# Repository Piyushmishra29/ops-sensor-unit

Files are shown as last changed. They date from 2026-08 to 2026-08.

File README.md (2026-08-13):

# OPS Sensor Unit

A rugged, field-style desk monitor for **air quality, temperature and humidity** — ESP32 + 1.3" OLED + MQ-135 + DHT11, in a 3D-printed enclosure designed around the actual parts rather than around a render.

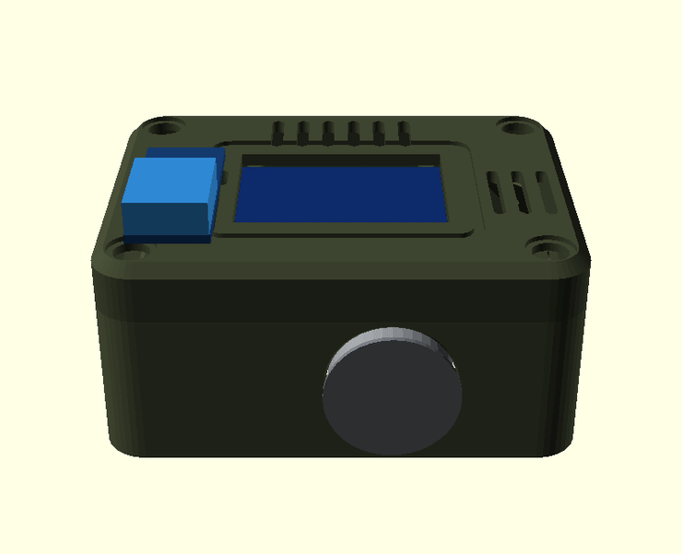
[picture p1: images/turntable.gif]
Assembled unit


**77.8 × 59.3 × 35.7 mm · two printed parts · ~44 g of filament · 1 h 23 m to print**

---

## What it measures — and what it doesn't

Being blunt about this up front, because most projects like this aren't:

| Claim | Reality |
|---|---|
| Temperature, humidity | ✅ DHT11 — ±2 °C, ±5 % RH. Coarse but honest. |
| "Air quality" | ⚠️ MQ-135 senses a **mixture of gases** (CO₂, VOCs, smoke, alcohol, NH₃) as a single resistance change. Useful as a *stale-air / smoke* indicator. |
| **AQI / PM2.5** | ❌ **Not possible with these parts.** An MQ-135 cannot see particulates. Anything labelling its output "AQI" is inventing a number. |

The firmware therefore reports an **AQ index** with a band (GOOD / FAIR / POOR / BAD), never a fake PM2.5 figure. If you want real PM2.5, add a PMS5003 or SDS011 — there is room in the case.

The MQ-135 also needs **24–48 h of burn-in** when new, and a few minutes of heater warm-up on every boot. The firmware shows a warm-up screen and refuses to present a reading as trustworthy before then.

---

## The enclosure

| | |
|---|---|
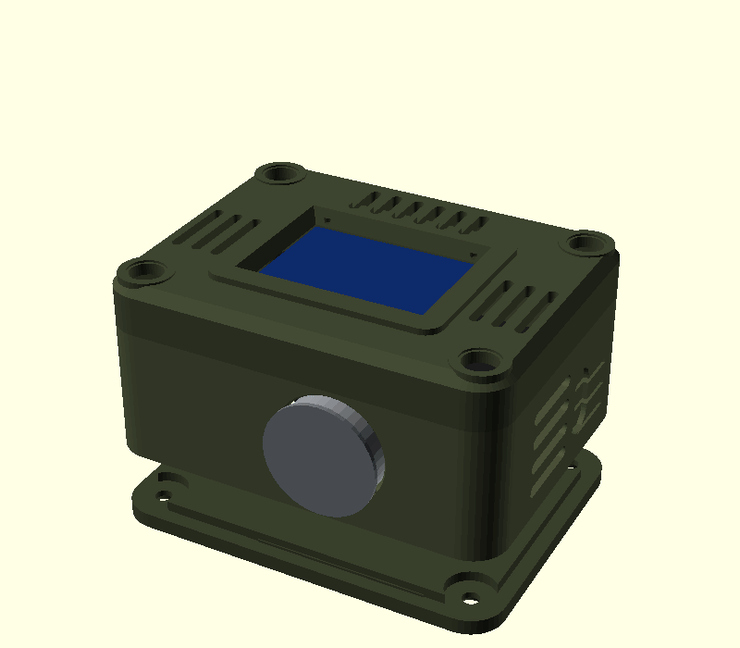
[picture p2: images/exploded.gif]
Exploded
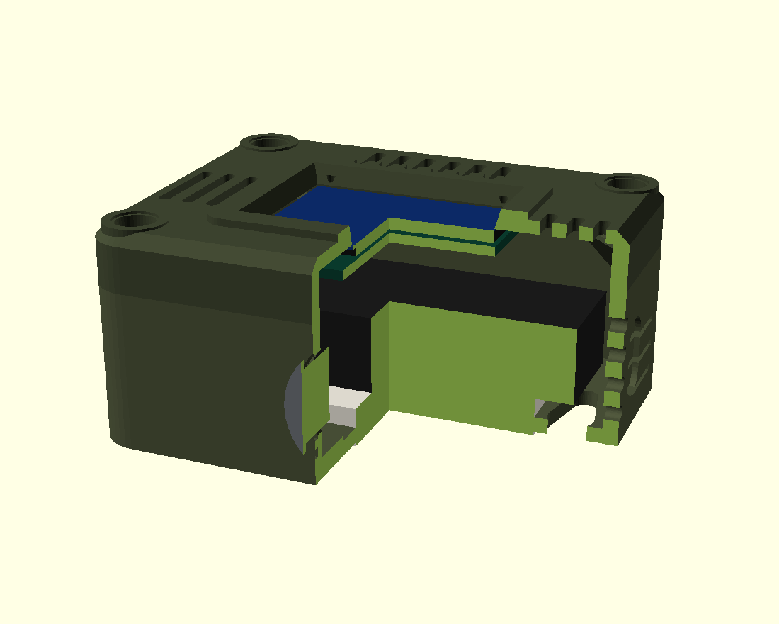
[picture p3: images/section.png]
Section
|  |  |
| Two-part shell: base tub + top cover, four M3 × 5 screws | Sectioned — the electronics are fully enclosed |
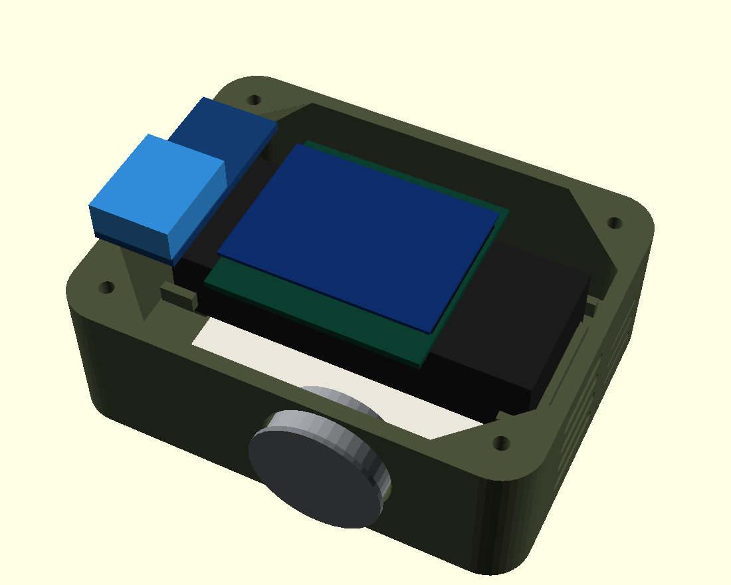
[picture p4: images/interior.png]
Interior
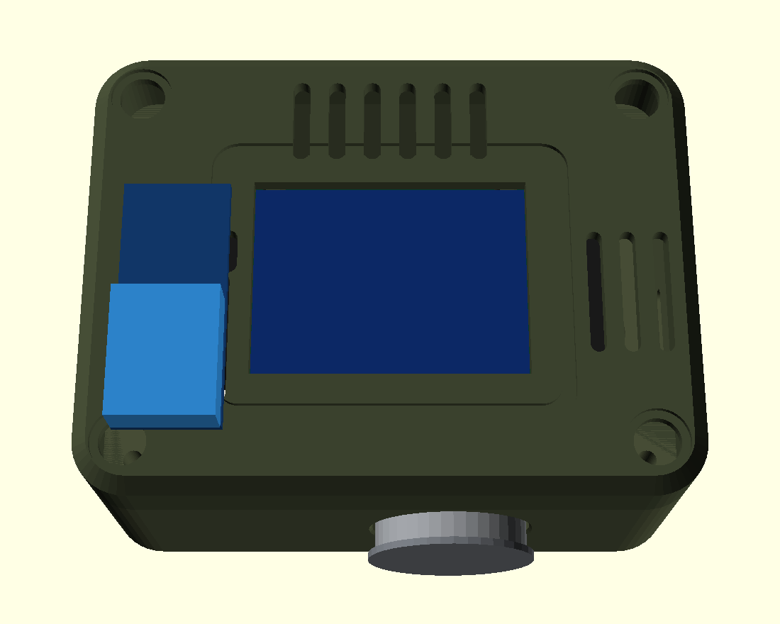
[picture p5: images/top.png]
Top
|  |  |
| Breadboard corner brackets, sensor supports, corner webs | Display window, vent fields, recessed screw pads |

**Design decisions worth knowing:**

- **Corner screw webs, not towers.** Each corner has a triangular gusset welded into the two walls — 13 mm legs tapering to 4 mm over 9 mm of height, a 45° self-supporting underside. 0.36 cm³ each instead of 1.56 cm³ as a column.
- **Sensors on perpendicular walls.** The MQ-135's heater runs hot enough to corrupt a nearby humidity reading, so the DHT11 sits on the left flank, 49 mm away, with its own vent field.
- **Breadboard is captive.** Four L-brackets hug the board's footprint with 0.3 mm clearance, on a raised pad.
- **Nothing needs support.** Both plates print flat as oriented.

### Dimensions

| Feature | Value |
|---|---|
| Outer | 77.8 × 59.3 × 35.7 mm |
| Interior | 72.6 × 54.1 × 28.5 mm |
| Wall / floor | 2.6 mm |
| Parting line | 26.1 mm |
| Display window | 34.8 × 25.8 mm |
| MQ-135 port | Ø20.8 mm, axis at z = 14.5 |
| USB-C | 13 × 7.4 mm racetrack, centre z = 12.3 |
| Fasteners | 4 × M3 × 5, self-tapping into the webs |

---

## Verification

The geometry was audited rather than eyeballed, because an earlier version of this design had seven clearance failures that only showed up under measurement:

- **47 parametric checks** across shell, component fit, display, sensors, ports, fasteners and floor features — all pass.
- **Mesh topology** — every part checked edge-by-edge: zero open, odd-count or non-manifold edges.
- **Cross-section scans** at four heights, hunting for unintended openings. The only enclosed voids are the two wall-mount keyholes.
- **Headless slice** of both plates: exit 0, no supports, 29.2 g / 52 min and 15.2 g / 31 min.

Defects this process caught and fixed: MQ-135 module passing through the floor, its port breaking the parting line, the module colliding with a corner post, the cavity eating the screw posts, blind screw bores creating sealed voids, louvre slots shooting out through the rear corners, USB-C 3 mm below the devkit's connector, keyholes sitting under the breadboard, and 0.77 mm of deck between the display window and a vent field.

---

## Printing

`print/OPS_ENCLOSURE_P2S.3mf` — Bambu Lab P2S, 0.2 mm, PLA, 3 walls, 20 % infill, 3 mm brim.

| Plate | Contents | Weight | Time |
|---|---|---|---|
| 1 | Base tub | 29.2 g | 52 min |
| 2 | Top cover + OLED clamp | 15.2 g | 31 min |

**Print plate 1 first and test-fit your components before committing to plate 2.** The enclosure is dimensioned from datasheet values for the devkit, MQ-135 and DHT11 modules; only the breadboard was measured from a real scan. See *Assumptions* below.

STLs are in `stl/`, and the parametric source is `cad/ops_unit.scad` — every dimension derives from the component constants at the top of that file, so changing a module size re-solves the case.

```bash
openscad -o base.stl  -D mode=1 cad/ops_unit.scad   # base tub
openscad -o cover.stl -D mode=2 cad/ops_unit.scad   # top cover
openscad -o clamp.stl -D mode=4 cad/ops_unit.scad   # OLED clamp
```

Modes: `0` assembly · `1` base · `2` cover · `3` exploded · `4` clamp · `7` section · `8` base with electronics.

### Assumptions to verify against your parts

| Part | Assumed | Check |
|---|---|---|
| ESP32-S3 devkit | 63 × 25.5 × 13 mm, USB-C at 12.3 mm | measure connector height |
| OLED | panel 34.8 × 23.2 (measured), M2 pitch 30.5 × 28.5 (assumed) | measure hole pitch |
| MQ-135 module | PCB 32 × 22, can Ø20 | measure |
| DHT11 module | 23 × 12 mm | measure |
| Mini breadboard | 50.14 × 38.54 × 6.5 | ✅ scanned |

---

## Firmware

`firmware/` — MicroPython, no network, no external libraries. See `firmware/README.md` for wiring and flashing.

The SH1106 driver is carried over from the author's *shopkeeper* project and keeps its comments: the 1.3" panel has 132 columns of RAM behind a 128-pixel display (so everything shifts 2 px without an offset), and the panel must be written before it is switched on or a marginal supply browns it out.

---

## Bill of materials

| Item | Notes |
|---|---|
| ESP32-S3 devkit | any board ≤ 63 mm long |
| 1.3" SH1106 OLED, I2C | **not** the 0.96" SSD1306 |
| MQ-135 module | analog output |
| DHT11 module | 3-pin breakout |
| Mini breadboard, 170 tie points | 50 × 38.5 mm |
| 4 × M3 × 5 screws | self-tapping into plastic |
| Jumper wires, USB-C cable | |

## Licence

MIT. Gridfinity-style: use it, change it, sell prints of it.

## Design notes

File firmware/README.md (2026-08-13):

# OPS Sensor Unit — firmware

MicroPython, offline, no external libraries. Verified running on an
**ESP32-WROOM-32D** with MicroPython v1.28.0.

## Wiring (classic ESP32 — NOT S3 pins)

| ESP32 | Component |
|---|---|
| GPIO21 | OLED SDA |
| GPIO22 | OLED SCL |
| 3V3 | OLED VCC + DHT11 VCC |
| GPIO4 | DHT11 DATA |
| GPIO34 | MQ-135 AOUT **via divider** |
| 5V / VIN | MQ-135 VCC (heater needs 5 V) |
| GPIO25 | optional button to GND |
| GND | OLED, DHT11, MQ-135, divider bottom |

**The divider is mandatory.** AOUT swings to 5 V; an ESP32 ADC pin is 3.3 V max.

```
MQ-135 AOUT ──[10k]──┬──► GPIO34
                     │
                  [15k]
                     │
                    GND
```

Pin rules on this chip: **GPIO6–11 are the SPI flash — never use them.**
GPIO0/2/12/15 are strapping pins. GPIO34–39 are input-only (fine for the
MQ-135, useless for the DHT11). The MQ-135 must sit on **ADC1** (GPIO32–39):
ADC2 stops working the moment anyone enables WiFi.

## Flashing

```bash
pip install esptool mpremote
esptool --port /dev/ttyUSB0 erase_flash
esptool --port /dev/ttyUSB0 --baud 460800 write_flash -z 0x1000 ESP32_GENERIC-*.bin
for f in sh1106.py config.py mq135.py aq.py display.py main.py boot.py; do
  mpremote connect /dev/ttyUSB0 cp $f :
done
mpremote connect /dev/ttyUSB0 run main.py     # or just reset — boot.py→main.py
```

## First run

1. **Warm-up** — 3 minutes on every boot. The display shows a countdown; no
   gas number is presented before it finishes, because a cold element reads
   high and falling.
2. **Burn-in** — a new MQ-135 wants 24–48 h powered before its baseline stops
   wandering. It responds to gas long before that; the absolute numbers just
   keep moving.
3. **Calibrate** — hold the button at boot for 3 s, **outdoors or at an open
   window**. This measures R0 against outdoor background CO₂ (421 ppm).
   Calibrating in a closed room bakes that room in and the unit reads it as
   perfect forever. Note a HEPA purifier's output is *not* a substitute: it
   removes particles and VOCs, not CO₂.

## What it measures

Temperature and humidity honestly (±2 °C, ±5 % RH). For air it reports an
**AQ index 0–100 with a band** (GOOD/FAIR/POOR/BAD) derived from Rs relative
to calibration-day Rs — a relative, single-sensor indicator of reducing gases
(CO₂, VOCs, smoke, alcohol, ammonia).

**It is not an AQI and cannot be.** An MQ-135 cannot see particulates. See the
comment block at the top of `aq.py`. Add a PMS5003/SDS011 for real PM2.5.

## Files

| File | Role |
|---|---|
| `config.py` | every pin, constant and threshold, with the reasoning |
| `sh1106.py` | 1.3" OLED driver (from the author's *shopkeeper* project) |
| `mq135.py` | ADC → Rs → Rs/R0 → ppm, calibration, T/RH correction, warm-up gate |
| `aq.py` | Rs → index and band, in log space |
| `display.py` | screens: main, detail, warm-up, calibration |
| `main.py` | init, sensor intervals, history, screen cycling, fault tolerance |

## Measured on hardware

| | |
|---|---|
| OLED | 0x3C on SDA 21 / SCL 22 |
| DHT11 | 27 °C, 62 % RH |
| MQ-135 | 1.54 V idle → Rs ≈ 13 kΩ |
| Filtered air vs room air | Rs **+11.7 %** in filtered air — correct polarity |

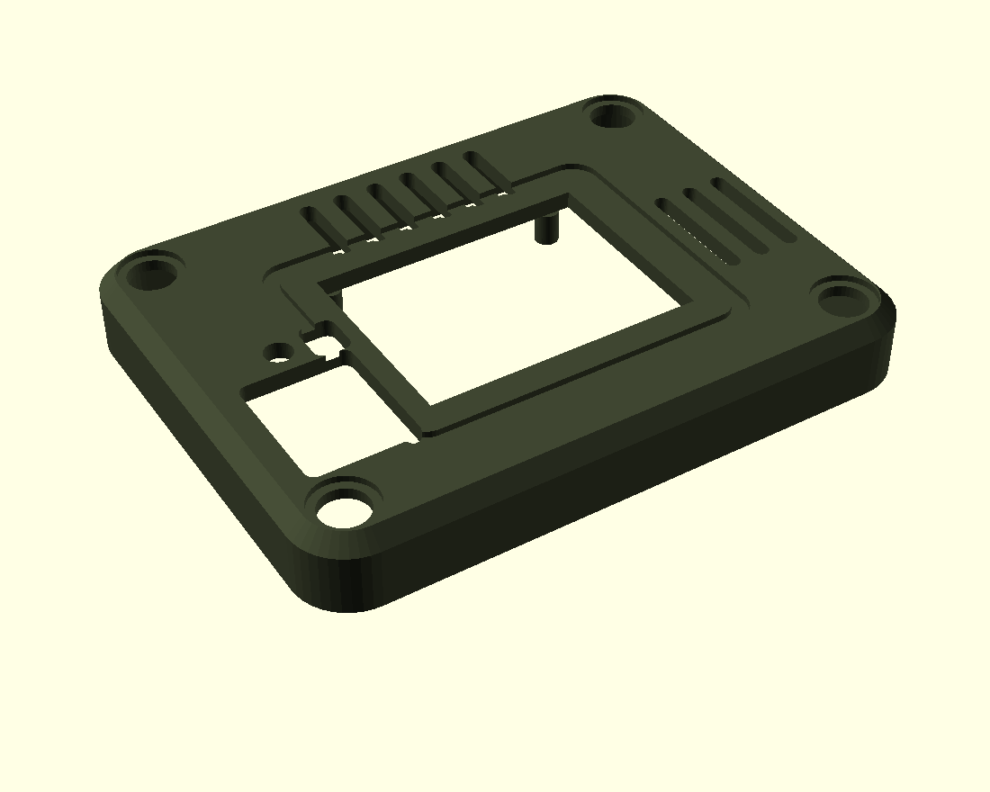
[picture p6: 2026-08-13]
images/cover.png

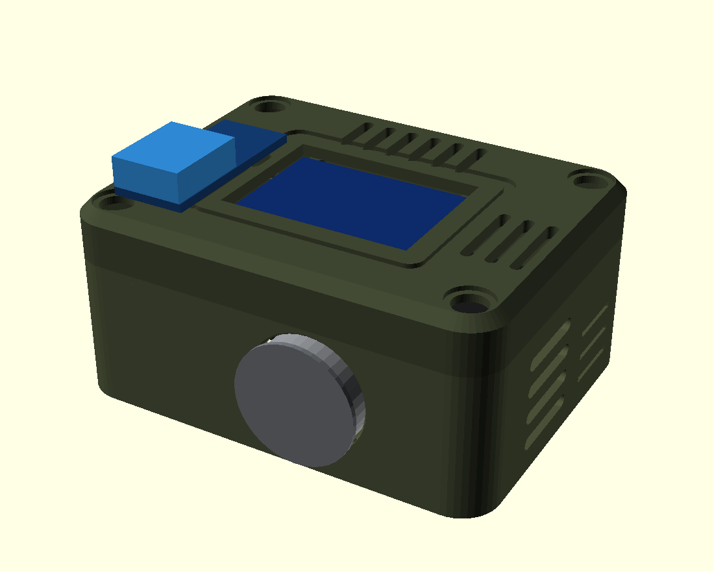
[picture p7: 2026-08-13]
images/hero.png

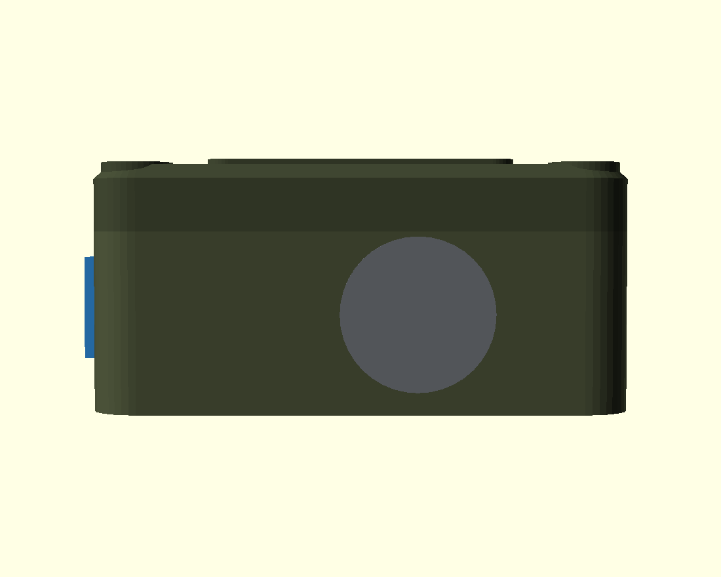
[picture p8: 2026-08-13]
images/front.png

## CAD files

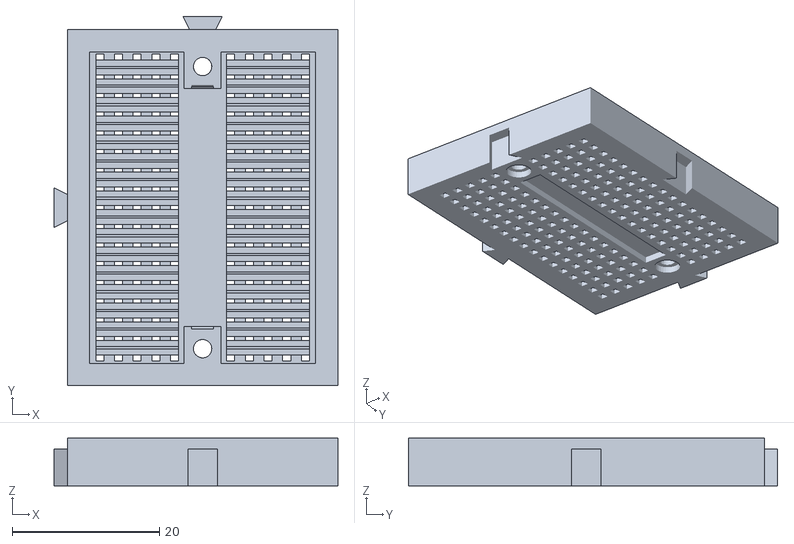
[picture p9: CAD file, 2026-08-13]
cad/breadboard_reference.stl
38.5 x 50.1 x 6.50

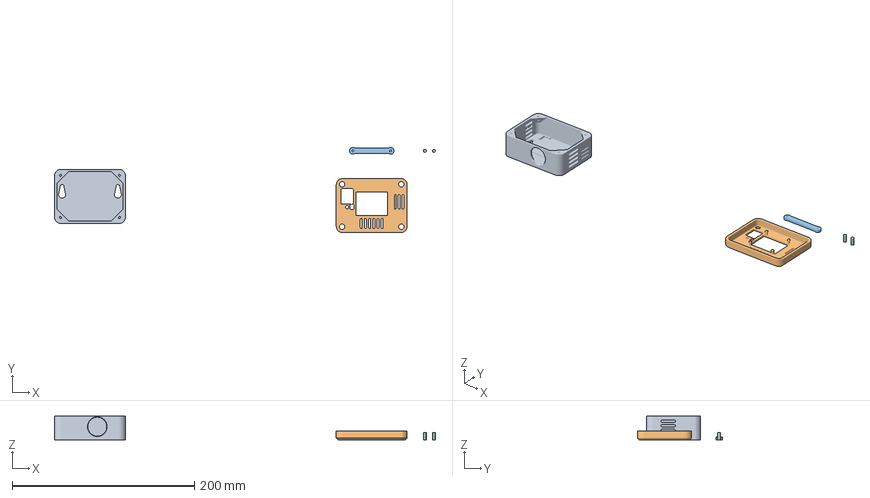
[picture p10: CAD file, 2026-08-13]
print/OPS_ENCLOSURE_P2S.3mf
417.6 x 93.4 x 26.1 mm
Base tub
Top cover
OLED clamp
DHT towers

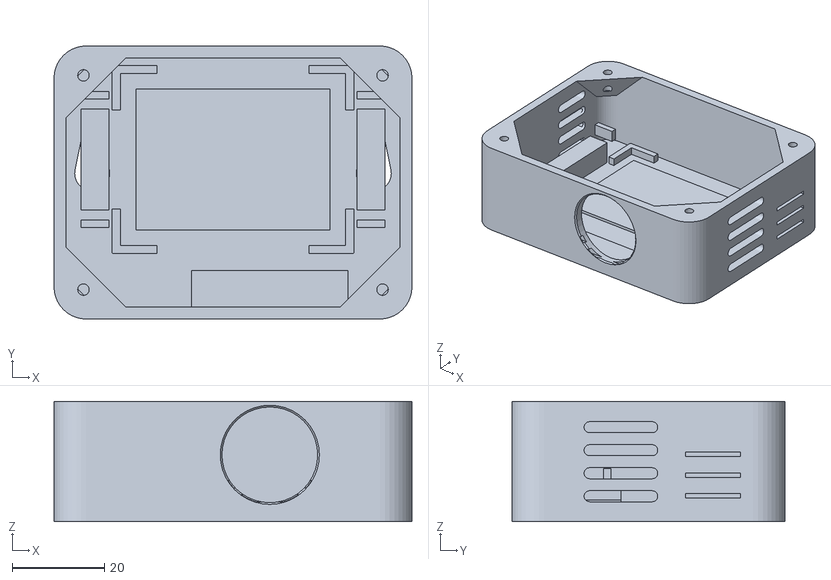
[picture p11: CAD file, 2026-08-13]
stl/ops_base.stl
77.8 x 59.3 x 26.1

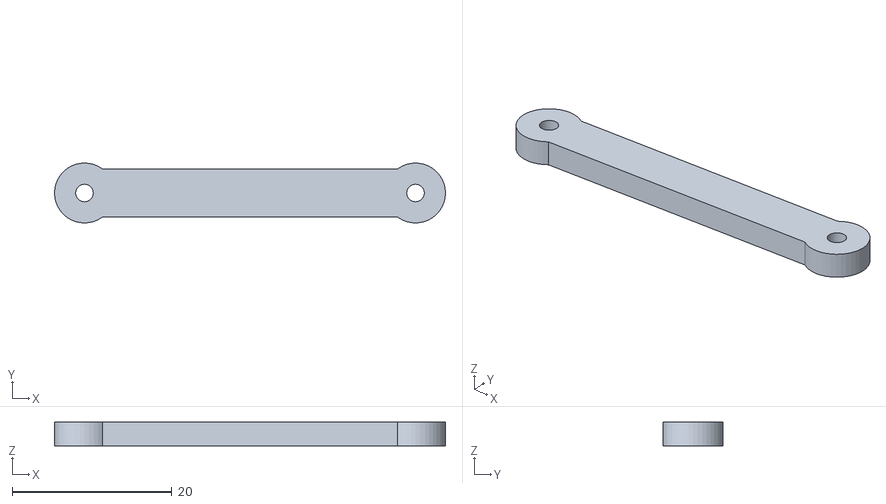
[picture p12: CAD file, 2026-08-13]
stl/ops_clamp.stl
48.9 x 7.50 x 3.00

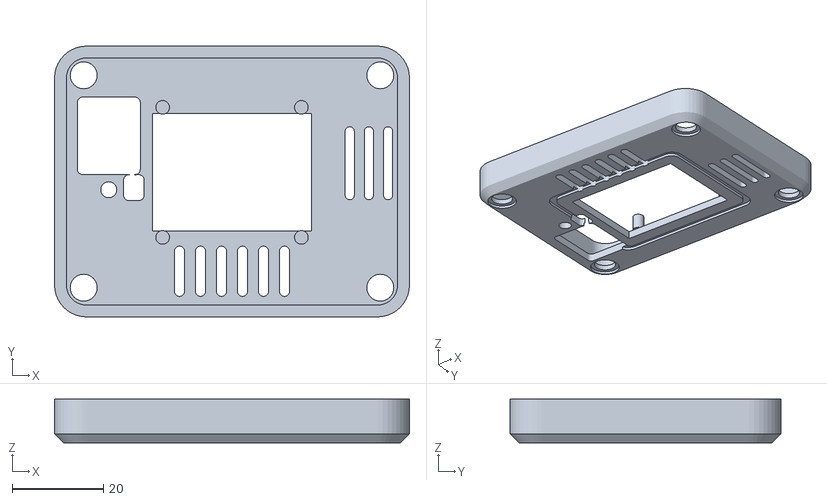
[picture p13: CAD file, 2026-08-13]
stl/ops_cover.stl
77.8 x 59.3 x 9.60

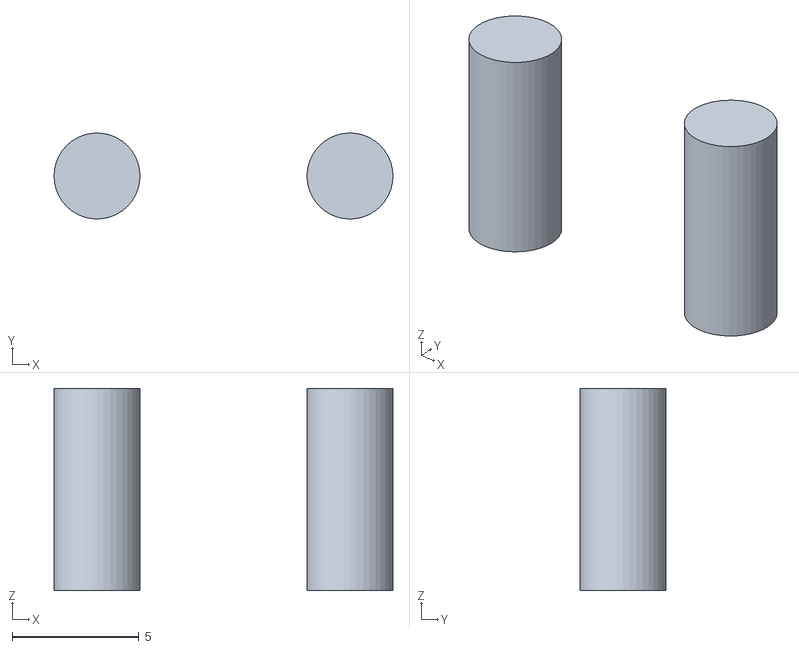
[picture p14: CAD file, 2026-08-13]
stl/ops_spacers.stl
13.4 x 3.40 x 8.00

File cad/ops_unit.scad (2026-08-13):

// ===========================================================================
// OPS SENSOR UNIT — ESP32 environmental monitor
// mode: 0 assembly | 1 base only | 2 cover only | 3 exploded
// ===========================================================================
mode = 0;
EXPLODE = 34;   // exploded-view gap, animatable
$fn = 40;

// ---- real component data --------------------------------------------------
BB      = [50.14, 38.54, 6.50];   // mini breadboard (bread.stl, measured)
ESP     = [63.0, 25.5, 13.0];     // ESP32-S3 DevKitC seated on the breadboard
// 1.3" SH1106 module. These are the MANUFACTURER'S DRAWING figures carried
// over from the author's shopkeeper project, where two caliper readings were
// proved wrong on the bench: the holes are 3.00 (M3) and the 4.0-4.5 reading
// was the copper annulus around them, and the board is 35.40 wide not 35.0.
OLED_PCB   = [35.40, 33.50, 1.20];
OLED_PANEL = [34.50, 23.00];      // glass, standing 1.4-1.5 proud of the PCB
OLED_GLASS = [34.8, 25.8];        // the cutout: clears the glass on both axes
OLED_HOLES = [30.40, 28.50];      // 2.50 inset all round: 35.40-5.00, 33.50-5.00
OLED_HOLE_D = 3.30;               // M3 clearance. NOT M2 - this cost a print once
// The display screws to four printed pillars hanging from the inside of the
// deck, rather than resting on a ledge. Printed deck-down the pillars point
// UP, so they cost nothing and need no support.
// The pillars are PEGS that enter the module's own 3.00 holes, not bosses
// sitting beside them: 2.90 across, which is a press fit in a printed 3.00
// hole and still assembles by hand. They locate the board in both axes and
// stop it rotating; the clamp holds it against them.
OLED_PIL_D  = 3.00;               // pushed to 3.00 - the module's hole size
OLED_PIL_H  = 4.2;                // through the 1.20 board, standing proud
// The active area is 29.42 x 14.70 and is NOT centred: it sits 2.05mm toward
// the header edge, because the driver IC and FPC bond eat the bottom 6.20mm of
// the glass. The cutout is 25.8 tall against a 14.70 active area, so the offset
// is absorbed - but a tight symmetric window would clip the status line.
MQ_CAN_D   = 20.0;                // MQ-135 steel can (protrudes, "half exposed")
MQ_PCB     = [32.0, 22.0, 2.0];
DHT_BODY   = [15.5, 12.0, 5.5];   // DHT11 blue body (protrudes)
DHT_PCB    = [23.0, 12.0, 2.0];

// ---- shell -----------------------------------------------------------------
WALL   = 2.6;
GAP    = 0.8;                     // wiring slack around the breadboard
FLOOR  = 2.6;
CORNER = 7.0;                     // corner radius, drives the rugged look
BOSS_IN = 1.8;                    // boss inset: keeps the screw well out of the cavity
BOSS_R = 4.6;                     // corner boss: sized for M3, not oversized
PLATE_T = 3.0;                    // bottom cover thickness
PLATE_CLR = 0.25;                 // slip fit of the plate into the body

// interior sized from the stack, not guessed
// ---- solved from the tolerance audit, not guessed ------------------------
IN  = [max(BB[0], ESP[0]) + 2*GAP + 8,      // 72.6  devkit + 4.8/side
       BB[1] + 2*GAP + 14,                  // 54.1  incl. 12.8mm front sensor bay
       BB[2] + ESP[2] + 9];                 // 28.5  display clears the devkit by 6.6
OUT = [IN[0] + 2*WALL, IN[1] + 2*WALL, IN[2] + FLOOR + WALL + 2];
SENS_AX = FLOOR + 11.9;                     // 14.5 sensor axis: port clears floor by 1.5
SPLIT   = SENS_AX + 11.6;                   // 26.1 MQ port sits wholly inside the base wall
BB_Y    = 5.0;                              // breadboard centre, 2.8mm rear gap

echo(str("OLED underside ", OUT[2]-WALL-4.4, "  vs devkit top ", FLOOR+BB[2]+ESP[2], " mm"));
echo(str("OUTER  ", OUT[0], " x ", OUT[1], " x ", OUT[2], " mm"));

// rounded slab: hull of 4 vertical cylinders
module rslab(sz, r, ch=0){
  hull() for(sx=[-1,1], sy=[-1,1])
    translate([sx*(sz[0]/2-r), sy*(sz[1]/2-r), 0])
      cylinder(h=sz[2], r=r);
}
// same but with a chamfered top edge (tapers in by `ch`)
module rslab_ch(sz, r, ch=1.6){
  hull(){
    rslab([sz[0], sz[1], sz[2]-ch], r);
    translate([0,0,sz[2]-ch]) rslab([sz[0]-2*ch, sz[1]-2*ch, ch], max(r-ch,0.6));
  }
}
// Screw corners are triangular webs spanning the two walls, not towers off the
// floor. Top face is full size, underside tapers 45 deg so it self-supports.
WEB_L = 13.0;    // leg length at the top
WEB_H = 9.0;     // height of the web (bottom legs = WEB_L - WEB_H -> 45 deg)
module corner_web(sx, sy, top){
  cx = sx*(OUT[0]/2-WALL); cy = sy*(OUT[1]/2-WALL);
  translate([cx, cy, top-WEB_H])
    hull(){
      translate([0,0,WEB_H-0.01])
        linear_extrude(0.01) polygon([[0,0], [-sx*WEB_L,0], [0,-sy*WEB_L]]);
      linear_extrude(0.01)
        polygon([[0,0], [-sx*(WEB_L-WEB_H),0], [0,-sy*(WEB_L-WEB_H)]]);
    }
}
module corner_bosses(h, r=BOSS_R, inset=BOSS_IN){
  for(sx=[-1,1], sy=[-1,1]) corner_web(sx, sy, h);
}
// M3 x 5 screws: only 2.0mm of cover under the head, so 3.0mm bites the post
module corner_screws(z0, deep=true){
  for(sx=[-1,1], sy=[-1,1])
    translate([sx*(OUT[0]/2-BOSS_R-BOSS_IN), sy*(OUT[1]/2-BOSS_R-BOSS_IN), 0]){
      translate([0,0,z0]) cylinder(h=40, d=3.2);                        // M3 shank, close clearance
      if(deep){
        translate([0,0,OUT[2]-7.6]) cylinder(h=9, d=5.9);               // head well: M3 cap is 5.5, pan 5.6
        translate([0,0,OUT[2]-8.5]) cylinder(h=1.0, d1=3.2, d2=5.9);
      }
    }
}
// Corner pads, cut INTO the deck rather than standing proud of it. Raised pads
// would be the only thing touching the plate when the cover prints face-down,
// which is the orientation that needs no support.
module corner_pads(){ }
module corner_pad_cuts(){
  for(sx=[-1,1], sy=[-1,1])
    translate([sx*(OUT[0]/2-BOSS_R-BOSS_IN), sy*(OUT[1]/2-BOSS_R-BOSS_IN), OUT[2]-0.8])
      difference(){ cylinder(h=2, r=BOSS_R-0.6); translate([0,0,-0.1]) cylinder(h=3, r=BOSS_R-2.1); }
}
// slots in a side wall: stacked in Z, running along Y, cutting through X
module louvres(n=5, len=17, w=2.2, pitch=4.4){
  for(i=[0:n-1]) translate([0, 0, (i-(n-1)/2)*pitch])
    hull() for(sy=[-1,1]) translate([0, sy*(len/2-w/2), 0])
      rotate([0,90,0]) cylinder(h=30, d=w, center=true);
}
// slots in the top skin: spaced in X, running along Y, cutting through Z
module top_slots(n=4, len=16, w=2.2, pitch=4.6){
  for(i=[0:n-1]) translate([(i-(n-1)/2)*pitch, 0, 0])
    hull() for(sy=[-1,1]) translate([0, sy*(len/2-w/2), 0]) cylinder(h=20, d=w, center=true);
}
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

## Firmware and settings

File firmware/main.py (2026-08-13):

"""
OPS Sensor Unit — main loop.

Shape of the thing:

    boot   -> bring up display, gas sensor, DHT11. None of them is allowed to
              be fatal: a unit with a dead screen must still sample, and a unit
              with a dead sensor must still say so on the screen.
    loop   -> poll each sensor on its own interval (the DHT11 cannot be rushed),
              fold the readings into one state dict, hand that to display.py.
    faults -> counted, not raised. A jumper that falls out mid-shift should
              degrade the display, not stop the device.

Timing is interval-based rather than sleep-based so that a slow DHT11 read
(they block for ~25 ms and sometimes much longer) does not drag the display
refresh with it.
"""
import gc
import sys
import time

from machine import Pin

import config
import aq
import display as ui
import mq135
import sh1106


# ── hardware, each optional ────────────────────────────────────────────────
def _init_display():
    try:
        d = sh1106.attach()
        if d:
            d.contrast(config.OLED_CONTRAST)
            d.fill(0)
            d.text("OPS SENSOR", 24, 20)
            d.text(config.FW, 48, 34)
            d.show()
        return d
    except Exception as e:
        print("display init failed:", e)
        return None


def _init_dht():
    """DHT11 on a bidirectional pin. Import guarded because a board without the
    dht module should still run the gas sensor."""
    try:
        import dht
        return dht.DHT11(Pin(config.DHT_PIN))
    except Exception as e:
        print("dht init failed:", e)
        return None


def _init_button():
    if config.BUTTON_PIN is None:
        return None
    try:
        return Pin(config.BUTTON_PIN, Pin.IN, Pin.PULL_UP)
    except Exception as e:
        print("button init failed:", e)
        return None


def _pressed(btn):
    if btn is None:
        return False
    v = btn.value()
    return (v == 0) if config.BUTTON_ACTIVE_LOW else (v == 1)


# ── calibration entry point ────────────────────────────────────────────────
def _maybe_calibrate(mq, d, btn):
    """Hold the button at boot to re-measure R0 in clean air.

    Deliberately gated behind a hold rather than a tap: calibrating in the
    wrong air bakes a bad baseline into every later reading, and it is the one
    action here that is hard to undo without a serial console.
    """
    if not _pressed(btn):
        return
    t0 = time.ticks_ms()
    while _pressed(btn):
        held = time.ticks_diff(time.ticks_ms(), t0) // 1000
        if d:
            d.fill(0)
            d.text("HOLD TO CAL", 20, 18)
            d.big(str(max(0, config.BUTTON_CAL_HOLD_S - held)), 56, 32, 2)
            d.show()
        if held >= config.BUTTON_CAL_HOLD_S:
            break
        time.sleep_ms(100)
    else:
        return                                  # released early: do nothing

    def progress(i, n, good):
        if d:
            ui.screen_cal(d, None, max(0, n - i), "%d ok" % good)
            d.show()

    try:
        r0, note = mq.calibrate(progress=progress)
        print("calibrated R0=%s (%s)" % (r0, note))
        if d:
            d.fill(0)
            d.text("CALIBRATED", 24, 20)
            d.text("R0 %d" % (r0 or 0), 32, 34)
            d.show()
            time.sleep(2)
    except Exception as e:
        print("calibration failed:", e)
        if d:
            d.fill(0); d.text("CAL FAILED", 24, 24); d.text(str(e)[:16], 0, 40)
            d.show(); time.sleep(3)


# ── main ───────────────────────────────────────────────────────────────────
def main():
    print("OPS Sensor Unit %s  fw %s" % (config.UNIT, config.FW))
    for note in config._self_check():
        print("config:", note)

    d = _init_display()
    mq = mq135.MQ135()
    dht_dev = _init_dht()
    btn = _init_button()
    _maybe_calibrate(mq, d, btn)

    wdt = None
    if config.WDT_ENABLE:
        try:
            from machine import WDT
            wdt = WDT(timeout=config.WDT_TIMEOUT_MS)
        except Exception as e:
            print("wdt unavailable:", e)

    temp = hum = None
    hist = []
    reading = mq.read()
    state = {"aq": aq.summary(reading), "raw": reading, "temp": None,
             "hum": None, "hist": hist, "screen": 0, "uptime_ms": 0}

    t_boot = time.ticks_ms()
    nxt_dht = nxt_mq = nxt_ui = nxt_hist = time.ticks_ms()
    nxt_rot = time.ticks_add(time.ticks_ms(), config.SCREEN_DWELL_S * 1000)
    fail_dht = fail_mq = fail_ui = 0
    btn_was = False

    while True:
        now = time.ticks_ms()

        # ── button: cycle screens, and pause auto-rotation while in use ────
        p = _pressed(btn)
        if p and not btn_was:
            state["screen"] = (state.get("screen", 0) + 1) % len(ui.SCREENS)
            nxt_rot = time.ticks_add(now, config.SCREEN_HOLD_S * 1000)
            nxt_ui = now                        # redraw immediately, feels crisp
        btn_was = p

        if time.ticks_diff(now, nxt_rot) >= 0:
            state["screen"] = (state.get("screen", 0) + 1) % len(ui.SCREENS)
            nxt_rot = time.ticks_add(now, config.SCREEN_DWELL_S * 1000)

        # ── DHT11: slow, fragile, and never allowed to stop the loop ───────
        if time.ticks_diff(now, nxt_dht) >= 0:
            nxt_dht = time.ticks_add(now, config.DHT_INTERVAL_MS)
            if dht_dev:
                try:
                    dht_dev.measure()
                    temp = dht_dev.temperature()
                    hum = dht_dev.humidity()
                    fail_dht = 0
                except Exception:
                    fail_dht += 1
                    if fail_dht >= config.FAIL_LIMIT_SENSOR:
                        temp = hum = None       # stop showing a stale number
            state["temp"], state["hum"] = temp, hum

        # ── MQ-135 ─────────────────────────────────────────────────────────
        if time.ticks_diff(now, nxt_mq) >= 0:
            nxt_mq = time.ticks_add(now, config.MQ_INTERVAL_MS)
            try:
                reading = mq.read(temp, hum)
                state["raw"] = reading
                state["aq"] = aq.summary(reading)
                fail_mq = 0
            except Exception as e:
                fail_mq += 1
                if fail_mq >= config.FAIL_LIMIT_SENSOR:
                    print("mq135 failing:", e)

        # ── history for the sparkline ──────────────────────────────────────
        if time.ticks_diff(now, nxt_hist) >= 0:
            nxt_hist = time.ticks_add(now, config.HISTORY_INTERVAL_S * 1000)
            hist.append(state["aq"].get("index"))
            while len(hist) > config.HISTORY_LEN:
                hist.pop(0)

        # ── draw ───────────────────────────────────────────────────────────
        if d and time.ticks_diff(now, nxt_ui) >= 0:
            nxt_ui = time.ticks_add(now, config.DISPLAY_INTERVAL_MS)
            state["uptime_ms"] = time.ticks_diff(now, t_boot)
            try:
                ui.render(d, state)
                d.show()
                fail_ui = 0
            except Exception as e:
                fail_ui += 1
                if fail_ui >= config.FAIL_LIMIT_DISPLAY:
                    print("display lost:", e)
                    d = None                    # keep sampling without it

        if wdt:
            wdt.feed()
        gc.collect()
        time.sleep_ms(config.LOOP_TICK_MS)


if __name__ == "__main__":
    try:
        main()
    except KeyboardInterrupt:
        print("stopped")
    except Exception:
        # Print the traceback and stop rather than reboot-looping: a unit that
        # reboots every 3 s is much harder to diagnose over a serial console
        # than one sitting at a prompt with the reason on screen.
        sys.print_exception(sys.exc_info()[1]) if hasattr(sys, "exc_info") else None
        raise

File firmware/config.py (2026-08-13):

"""
OPS sensor unit — configuration.

EVERYTHING a given build needs to differ on lives here: pins, the divider
resistors, the gas curve constants, every interval and every threshold. No
other file in this firmware contains a bare number that a person would want to
change. If you find yourself editing mq135.py or display.py to tune something,
that is a bug in this file.

    ┌──────────────────────────────────────────────────────────────────────┐
    │ THE PIN NUMBERS BELOW ARE A CHOICE, NOT A DISCOVERY.                  │
    │ They are sane ESP32-S3 defaults picked to avoid the strapping pins,   │
    │ the USB pins and the SPI-flash pins - but the firmware cannot see     │
    │ your breadboard. Make these match your wiring, or make your wiring    │
    │ match these. Nothing here is auto-detected except the OLED's I2C      │
    │ address.                                                             │
    └──────────────────────────────────────────────────────────────────────┘

Calibration (R0) is NOT in this file. It is measured per unit, per sensor, in
clean air, and persisted to /data/cal.json - because R0 is a property of the
individual bead you soldered, not of the design. See mq135.calibrate().

MicroPython note: this module is imported very early, so it must not touch
`machine` or any hardware. It is arithmetic and constants only.
"""
import math


# ── identity ───────────────────────────────────────────────────────────────
UNIT = "OPS-0001"
FW = "1.0.0"

DATA_DIR = "/data"


# ══ PINS ═══════════════════════════════════════════════════════════════════
# BOARD: ESP32-WROOM-32D  (classic Xtensa dual-core ESP32, NOT an S3).
# The two parts have completely different pinouts, so these numbers are not
# interchangeable with S3 examples found online.
#
# Pins deliberately avoided on this part, and why:
#   GPIO6..GPIO11    SPI flash. Connecting ANYTHING here stops the board
#                    booting. This is the one mistake that looks like a dead
#                    board rather than a wiring error.
#   GPIO0, 2, 12, 15 strapping pins, sampled at reset. Held wrong, the board
#                    either drops into the bootloader or refuses to start.
#                    GPIO12 in particular sets flash voltage - pulling it high
#                    at boot can brown out the flash.
#   GPIO34..GPIO39   INPUT ONLY. No output driver, no internal pull-ups.
#                    Perfect for an analog input, useless for the DHT11 (which
#                    is bidirectional) and useless for a button that wants a
#                    pull-up.
#
# ADC map, which decides where the gas sensor goes:
#   ADC1 = GPIO32..39   <- usable always
#   ADC2 = GPIO0,2,4,12..15,25..27  <- DEAD whenever WiFi is active

# ── display: 1.3" SH1106 over I2C ──────────────────────────────────────────
# The 1.3" panel is an SH1106 and needs a 2-column offset; the 0.96" is an
# SSD1306 and does not. See firmware/sh1106.py for that and for the
# write-the-frame-before-you-light-it rule this part demands.
OLED = True
OLED_SDA = 21             # classic ESP32 default I2C pair
OLED_SCL = 22
OLED_ADDR = 0x3C          # 0x3D on a few modules; sh1106.attach() scans for this
OLED_FREQ = 400000        # 400 kHz. At 100 kHz a full frame takes ~108 ms, which
                          # turns a 1 Hz refresh into a visible slideshow.
OLED_CONTRAST = 0x95

# ── MQ-135 analog gas sensor ───────────────────────────────────────────────
# MUST be an ADC1 pin (GPIO32..39). ADC2 is shared with the radio: there is no
# WiFi in this firmware so ADC2 would work today, but the moment anyone adds
# networking those reads start returning garbage, and that is a very unpleasant
# bug to meet later. GPIO34 is ADC1_CH6 and is input-only, which is exactly
# what an analog input wants.
MQ135_PIN = 34

# ── DHT11 temperature / humidity ───────────────────────────────────────────
# Any bidirectional GPIO - NOT one of GPIO34..39, which cannot drive the line.
# Needs a 4.7k-10k pull-up to 3V3 on the data line; most 3-pin DHT11 breakout
# boards already have one fitted, bare 4-pin parts do not.
DHT_PIN = 4

# ── screen-cycle button (OPTIONAL) ─────────────────────────────────────────
# Set to None if you did not fit one — the firmware then auto-rotates screens
# on a timer and never touches the pin. A momentary switch to GND; the internal
# pull-up does the rest, so no external resistor.
# The devkit's own BOOT button is GPIO0 and would work, but holding GPIO0 low
# across a reset drops the chip into the bootloader, so it is a poor choice for
# a button people are meant to press casually.
BUTTON_PIN = 25
BUTTON_ACTIVE_LOW = True
BUTTON_DEBOUNCE_MS = 40
BUTTON_CAL_HOLD_S = 3      # hold at boot to start a clean-air calibration
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

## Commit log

2026-08-13 OPS Sensor Unit: parametric enclosure, verified geometry, renders
    ESP32 + SH1106 1.3in OLED + MQ-135 + DHT11 environmental monitor in a
    rugged printed case. Geometry derived from component dimensions and audited:
    47 parametric clearance checks, mesh topology verified watertight,
    cross-section scans for stray openings, both plates slice clean.
    [OPS_ENCLOSURE_P2S.3mf, breadboard_reference.stl, ops_base.stl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]
2026-08-13 Firmware: complete, flashed and verified on hardware
    MicroPython 1.28 on ESP32-WROOM-32D. Pins corrected from S3 to classic ESP32
    (I2C 21/22, MQ-135 on ADC1 GPIO34, DHT11 GPIO4, button GPIO25).
    Verified on the bench: OLED at 0x3C, DHT11 reading 27C/62%, MQ-135 at 1.54V.
    Filtered air vs room air shows Rs +11.7% with a smooth monotonic decay back
    to room baseline - correct polarity, sensor confirmed working.
    aq.py reports an AQ index, never a fake AQI/PM2.5 - an MQ-135 cannot see
    particulates and the module says so at length.
    [aq.py, config.py, display.py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]
2026-08-13 Enclosure: part-sized mounts, ESP32 support, straight window; UI rework
    Mounts now match the measured parts rather than generic bosses:
    - display on four 3.00 towers at its own 30.40 x 28.50 pitch
    - DHT11 on a 3.40 press-in tower through its 3.50 hole, one continuous
    22.7mm opening for the body and the LED
    - body screws tightened to true M3 (3.2 shank, 5.9 head well)
    - display window straightened; all flaring removed
    - ESP32 saddles carry the 6.4mm the devkit overhangs the breadboard
    Cover prints deck-down with no support, so every boss and peg points inward
    and the bezel and corner pads are recessed rather than raised.
    Display UI reworked for a 1-bit panel: inverted band strip, 3x headl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
    [OPS_ENCLOSURE_P2S.3mf, ops_base.stl, ops_clamp.stl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]
